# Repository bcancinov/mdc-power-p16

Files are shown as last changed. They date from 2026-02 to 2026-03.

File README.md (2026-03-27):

# mdc-power-p16
Modular Detector Controller Power 16V DC-DC Mezzanine Module

## Overview
12V input to 16V output DC-DC module, 0.5A nominal output, used as one of the `mdc-power-*` bias rails.
Designed for 2 MHz sync operation.
Mezzanine module.

## Power Stage
- Controller: `LT8350S` (`U1`)
  - 4-switch, single-inductor synchronous buck-boost controller (Silent Switcher 2 family).
  - Supports input above/below VOUT, suitable for regulated 16V from 12V input.
  - Silent Switcher 2 architecture for reduced EMI and cleaner switch-node behavior.
  - Single-inductor buck-boost topology simplifies power stage while handling input transients.
- Inductor: `L1` = `3.3uH`
  - Uses the XGL4020 shielded power inductor family (see `docs/xgl4020.pdf`).
  - Shielded construction to reduce radiated EMI and coupling into sensitive nodes.
  - Very low DCR family to reduce copper loss and improve efficiency.
  - Low AC loss construction optimized for high-frequency switching.

## Files
- Schematic: `power_p16.pdf`
- Simulation: `sim/` (LTspice and LTpowerCAD files used for loop and transient checks)

## Board Dimensions
- 44.8 mm x 41.5 mm

## Board Stackup
- 4-layer PCB

## CAD
- Designed using KiCad 9.

## Interface
- Control pins: `EN` (enable) and `PG` / `~PGOOD` (power good).
- Connector: `LSHM-140-04.0-L-DV-A-N-K-TR` (Samtec LSHM series) mezzanine for power and control signals.
  - Common pinout is shared across the 16V, -16V, 6V, and 3.3V variants.
  - Unused output rails are tied to GND on the specific module variant.

## Images
Layout:
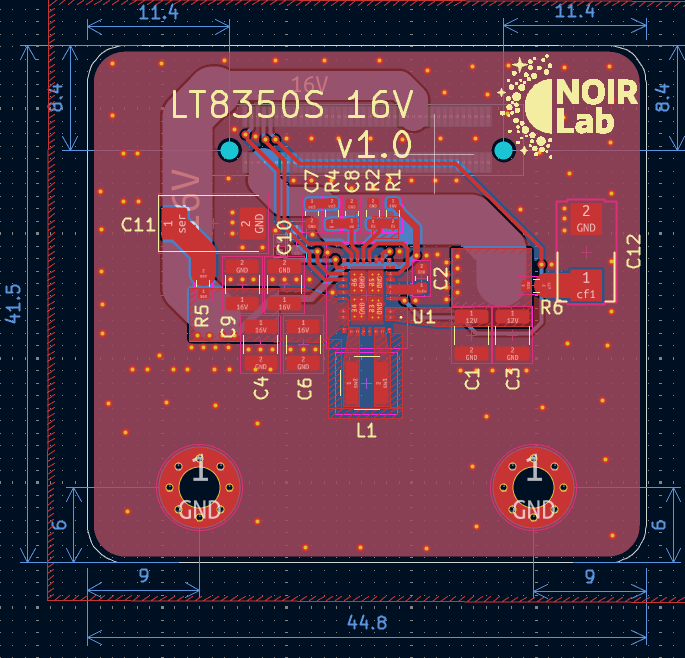
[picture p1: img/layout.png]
Layout


3D view:
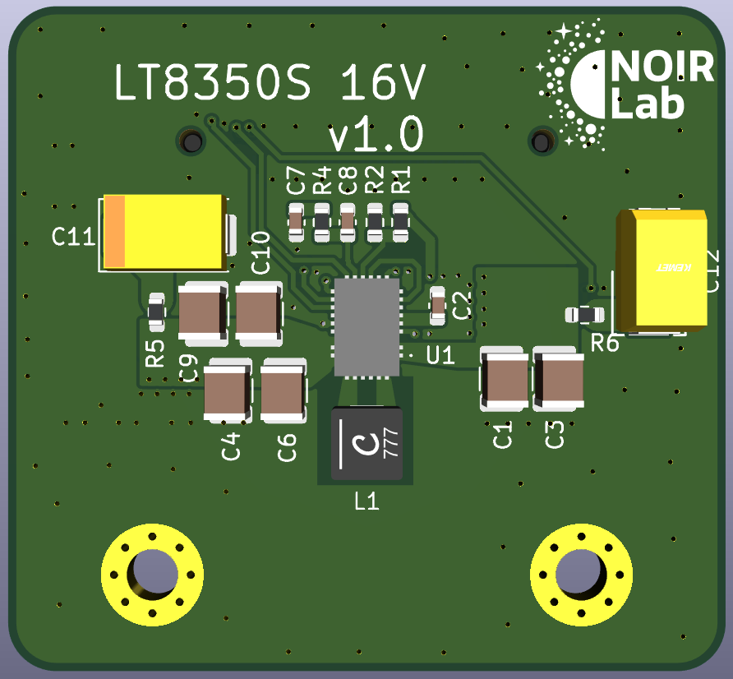
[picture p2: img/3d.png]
3D view


## License

This hardware design is licensed under the **Creative Commons Attribution-NonCommercial-ShareAlike 4.0 International License** (CC BY-NC-SA 4.0).

You are free to download, modify, and build upon this design for your own research or personal use, provided you give appropriate credit and share your modifications under the exact same license. **Commercial manufacturing or use of these designs is strictly prohibited without explicit permission.**

To view a copy of this license, visit [http://creativecommons.org/licenses/by-nc-sa/4.0/](http://creativecommons.org/licenses/by-nc-sa/4.0/) or see the `LICENSE` file in this repository.

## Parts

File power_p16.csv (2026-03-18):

Reference | Qty | MPN | M | Description
C1,C3 | 2 | GCM32ER71H475KA55K | Murata | 4.7 µF ±10% 50V Ceramic Capacitor X7R 1210 (3225 Metric)
C2 | 1 | GCM188R71E105KA64D | Murata | 1 µF ±10% 25V Ceramic Capacitor X7R 0603 (1608 Metric)
C4,C6,C9,C10 | 4 | TMK325ABJ476MM-P | TAIYO YUDEN | 47 µF ±20% 25V Ceramic Capacitor X5R 1210 (3225 Metric)
C5 | 1 | GCM155R71H104KE02J | MURATA | 0.1 µF ±10% 50V Ceramic Capacitor X7R 0402 (1005 Metric)
C7 | 1 | GRT1885C1E103FA02D | Murata | 10000 pF ±1% 25V Ceramic Capacitor C0G, NP0 0603 (1608 Metric)
C8 | 1 | CBR06C519C5GACAUTO | KEMET | 5.1 pF ±0.25pF 50V Ceramic Capacitor C0G, NP0 0603 (1608 Metric)
C11 | 1 | T521V226M025ATE040 | KEMET | 22 µF Molded Tantalum Polymer Capacitor 25 V 2917 (7343 Metric) 40mOhm @ 100kHz
C12 | 1 | T521X107M025ATE060 | Kemet | 100 µF Molded Tantalum Polymer Capacitor 25 V 2917 (7343 Metric) 60mOhm @ 100kHz
H1,H2 | 2 |  |  | Mounting Hole with connection
J1 | 1 | LSHM-140-04.0-L-DV-A-N-K-TR | Samtec | 80 Position Connector Self Mating, Non-Gendered, Hermaphroditic Surface Mount Gold
L1 | 1 | XGL4020-332MEC | Coilcraft | 3.3 µH Shielded Molded Inductor 6.6 A 34mOhm Max 1616 (4040 Metric)
R1 | 1 | ERA-3AEB114V | Panasonic | 110 kOhms ±0.1% 0.1W, 1/10W Chip Resistor 0603 (1608 Metric) Automotive AEC-Q200 Thin Film
R2 | 1 | ERA-3AEB7321V | Panasonic | 7.32 kOhms ±0.1% 0.1W, 1/10W Chip Resistor 0603 (1608 Metric) Automotive AEC-Q200 Thin Film
R3 | 1 | CRCW060320K0FKEA | VISHAY | 20 kOhms ±1% 0.1W, 1/10W Chip Resistor 0603 (1608 Metric) Automotive AEC-Q200 Thick Film
R4 | 1 | CRCW060347K5FKEA | Vishay | 47.5 kOhms ±1% 0.125W, 1/8W Chip Resistor 0603 (1608 Metric) Automotive AEC-Q200 Thick Film
R5,R6 | 2 | RCWE0603R500FKEA | Vishay | 500 mOhms ±1% 0.2W, 1/5W Chip Resistor 0603 (1608 Metric) Automotive AEC-Q200, Current Sense, Moisture Resistant Thick Film
U1 | 1 | LT8350SAV#PBF | Analog | Buck-Boost Switching Regulator IC Positive Adjustable 1V 1 Output 6A 32-TFQFN Exposed Pad, 28 Leads

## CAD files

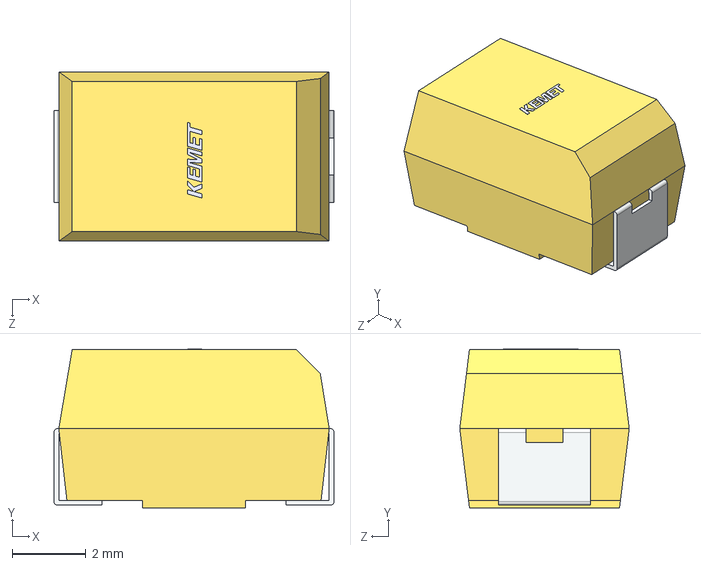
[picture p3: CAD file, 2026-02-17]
step/T521X.step
7.60 x 4.30 x 4.60 mm

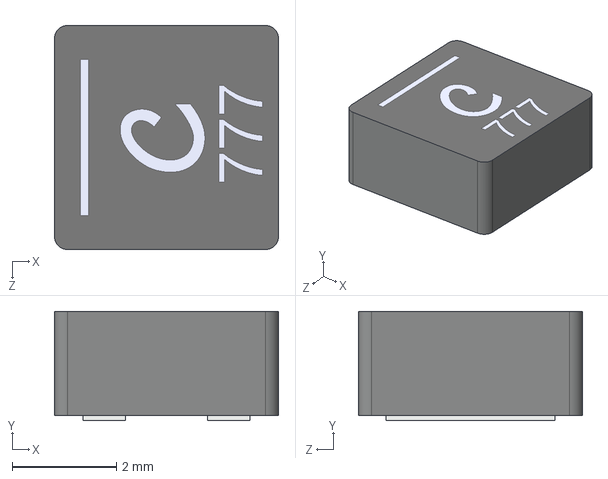
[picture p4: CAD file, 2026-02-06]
step/Coilcraft-XGL4020.step
4.30 x 2.10 x 4.30 mm

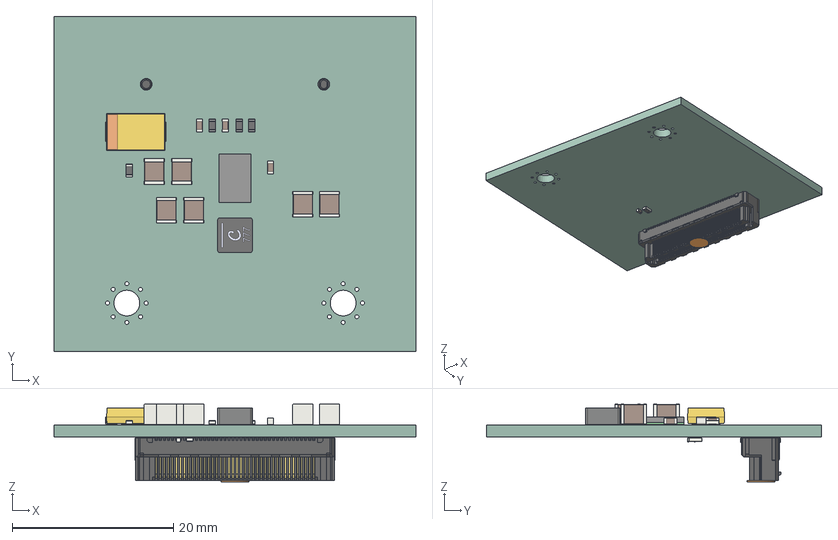
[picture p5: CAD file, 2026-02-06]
step/power_p16.step
44.8 x 41.5 x 9.63 mm
Coilcraft-XGL4020
C_1210_3225Metric x 6
R_0603_1608Metric x 5
C_0603_1608Metric x 3
CP_EIA-7343-20_Kemet-V
LT8350SAV#PBF
C_0402_1005Metric
LSHM-40-04.0-DV-A-N_STRIP
C-185--40-04.0-L-DV1P
C-185--40-04.0-DV1P2 L
K-DOT-.138-.250-.005.pp
power_p16_PCB

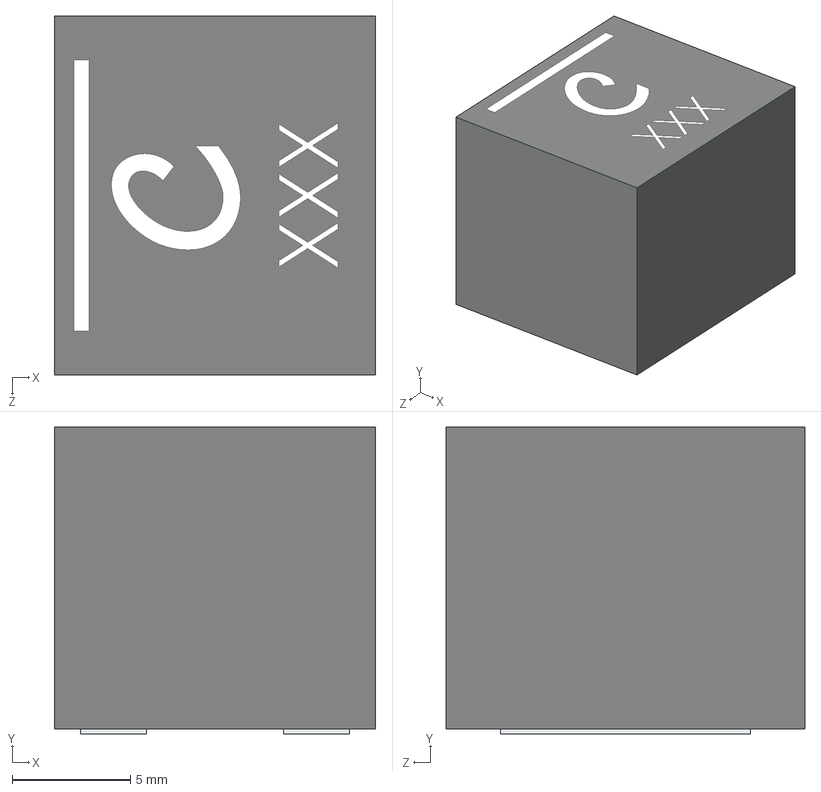
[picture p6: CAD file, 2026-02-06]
step/Coilcraft-XGL1313.step
13.6 x 13.0 x 15.2 mm

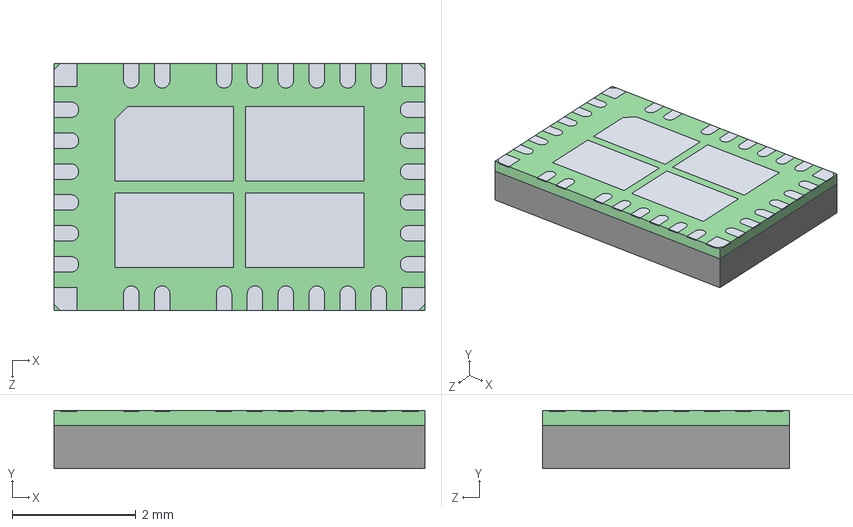
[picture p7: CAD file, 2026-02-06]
step/LT8350SAV#PBF.stp
6.00 x 0.94 x 4.00 mm

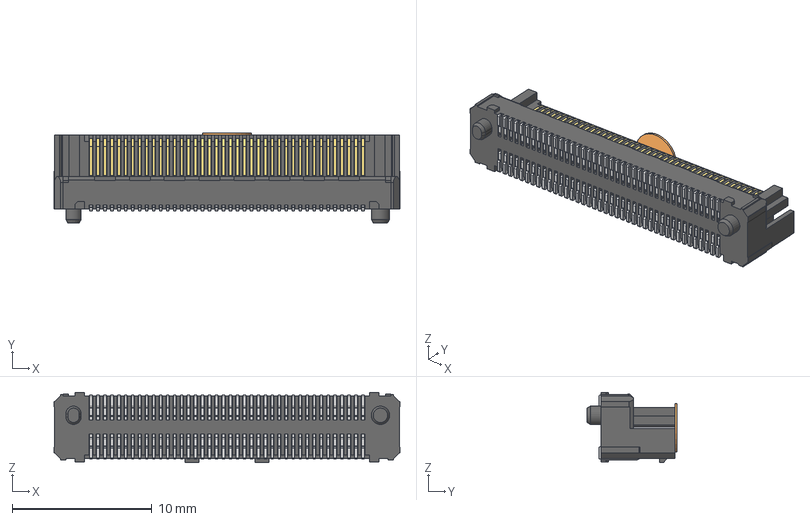
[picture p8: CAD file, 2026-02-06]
step/LSHM-140-04.0-L-DV-A-N-K-TR.stp
24.8 x 6.45 x 5.03 mm
LSHM-40-04.0-DV-A-N_STRIP
C-185--40-04.0-L-DV1P
C-185--40-04.0-DV1P2 L
K-DOT-.138-.250-.005.pp

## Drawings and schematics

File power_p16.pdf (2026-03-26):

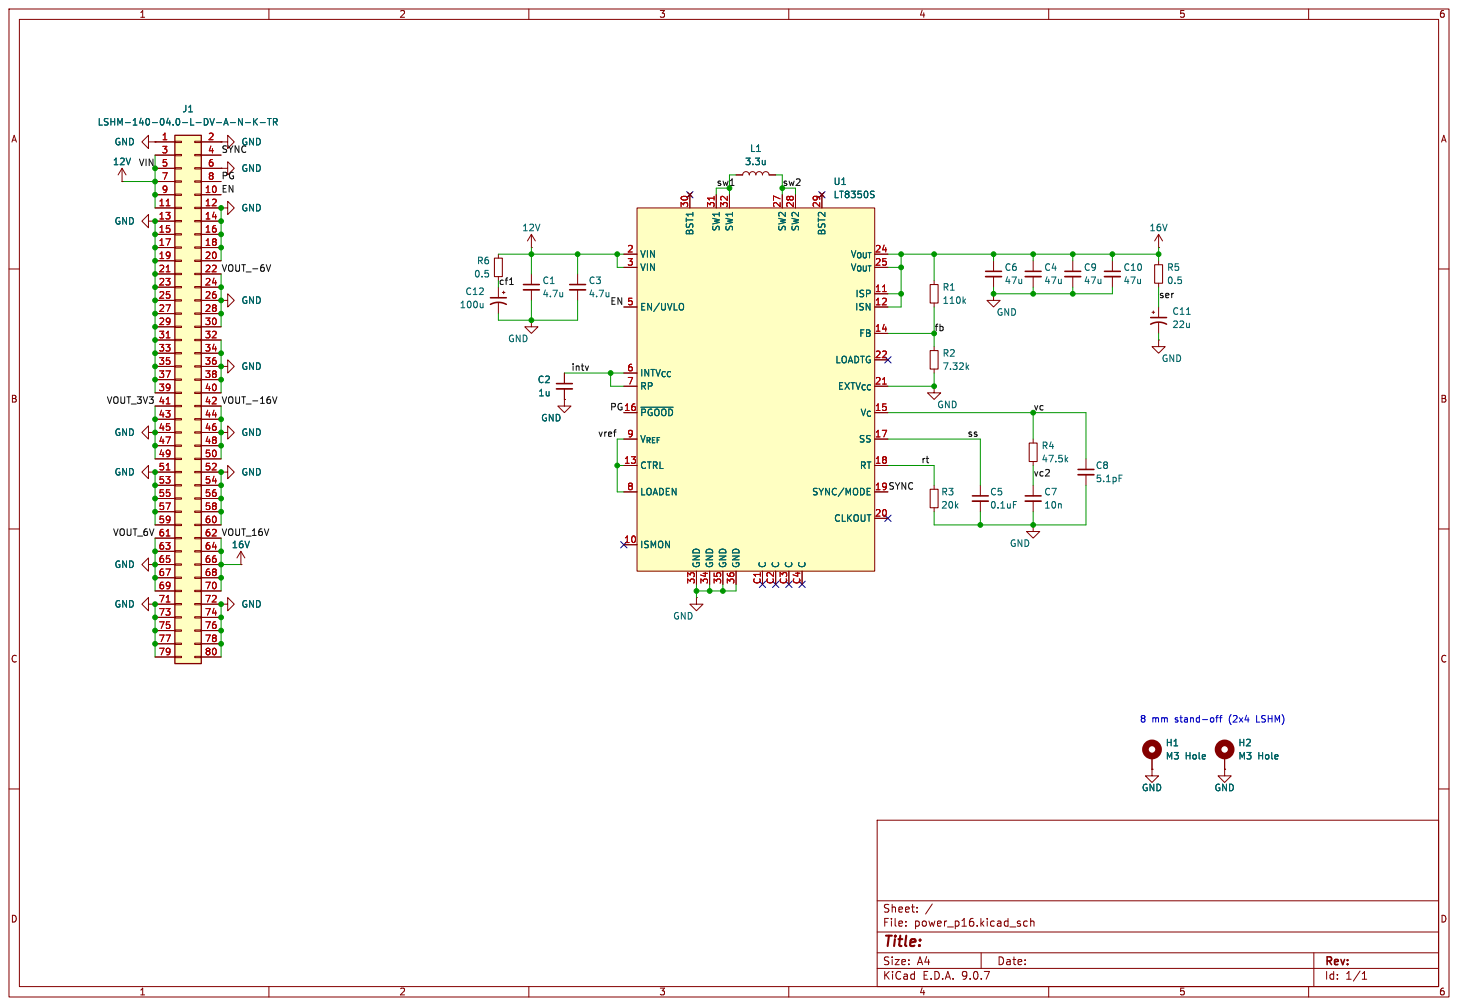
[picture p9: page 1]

Id: 1/1 Title: File: power_p16.kicad_sch Sheet: / GND

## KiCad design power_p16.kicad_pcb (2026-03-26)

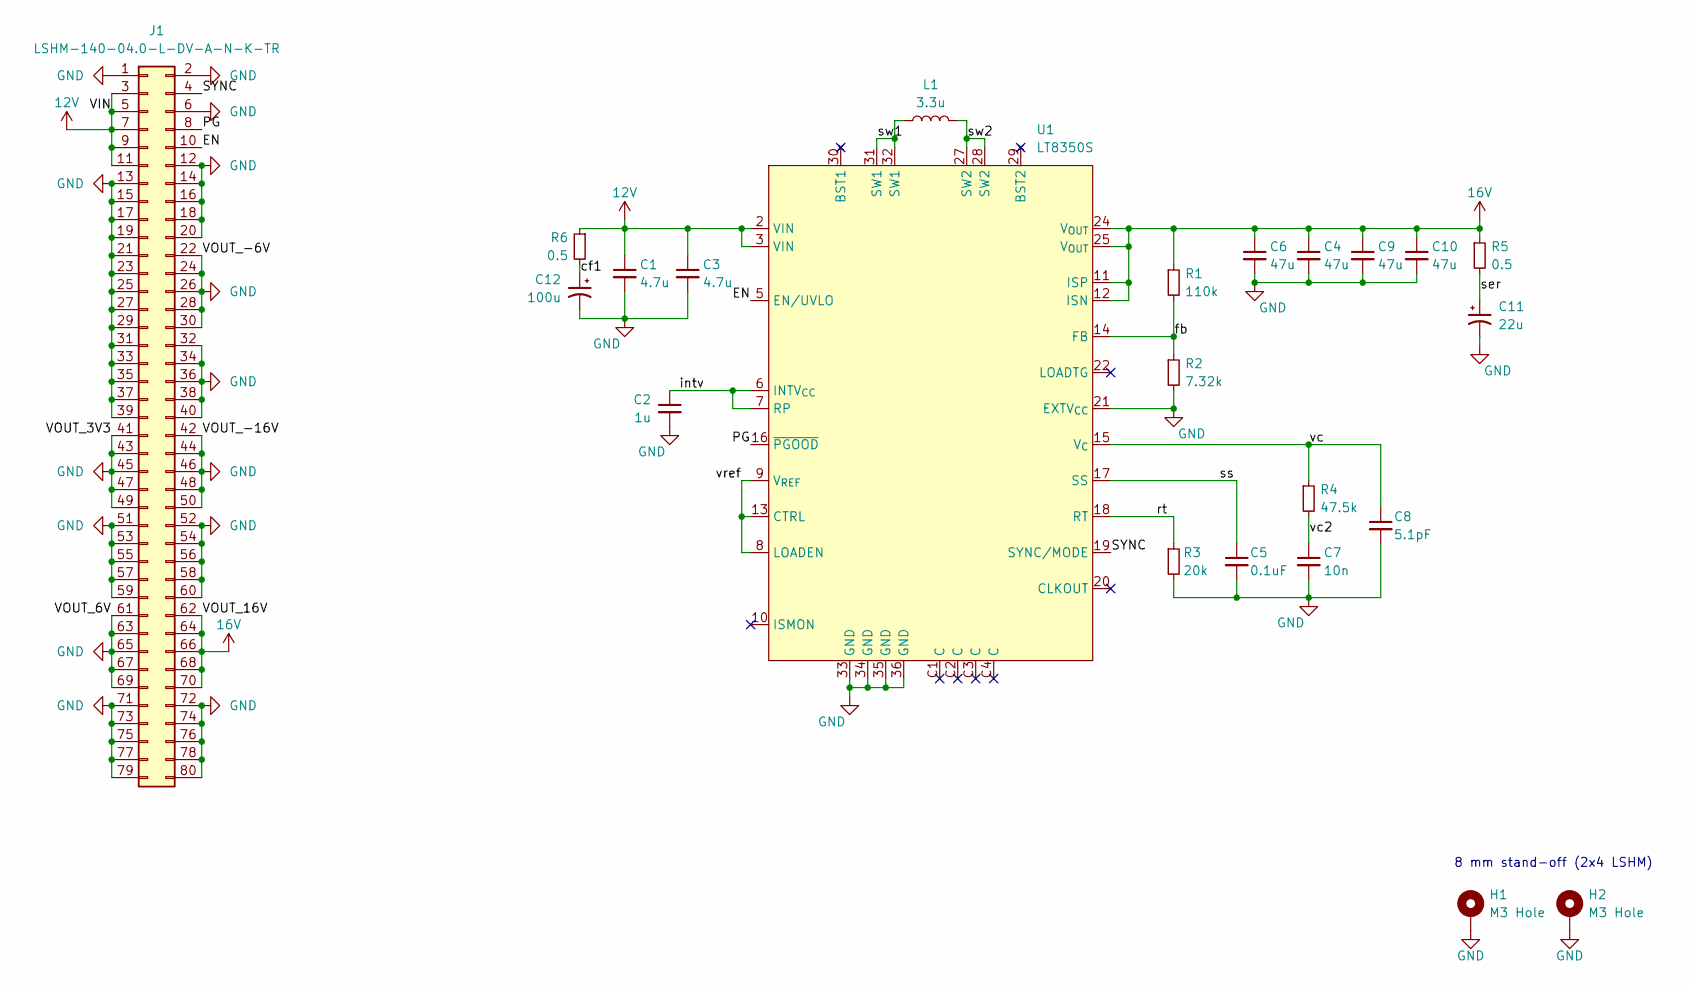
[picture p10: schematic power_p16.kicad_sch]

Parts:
C1, C3: 4.7u; C_1210_3225Metric; MPN GCM32ER71H475KA55K
C2: 1u; C_0603_1608Metric; MPN GCM188R71E105KA64D
C4, C6, C9, C10: 47u; C_1210_3225Metric; MPN TMK325ABJ476MM-P
C5: 0.1uF; C_0402_1005Metric; MPN GCM155R71H104KE02J
C7: 10n; C_0603_1608Metric; MPN GRT1885C1E103FA02D
C8: 5.1pF; C_0603_1608Metric; MPN CBR06C519C5GACAUTO
C11: 22u; CP_EIA-7343-20_Kemet-V; MPN T521V226M025ATE040
C12: 100u; T521X; MPN T521X107M025ATE060
H1, H2: M3 Hole; MountingHole_3.2mm_M3_Pad_Via
J1: LSHM-140-04.0-L-DV-A-N-K-TR; SAMTEC_LSHM-140-04.0-L-DV-A-N-K-TR; MPN LSHM-140-04.0-L-DV-A-N-K-TR
L1: 3.3u; XGL4020; MPN XGL4020-332MEC
R1: 110k; R_0603_1608Metric; MPN ERA-3AEB114V
R2: 7.32k; R_0603_1608Metric; MPN ERA-3AEB7321V
R3: 20k; R_0603_1608Metric; MPN CRCW060320K0FKEA
R4: 47.5k; R_0603_1608Metric; MPN CRCW060347K5FKEA
R5, R6: 0.5; R_0603_1608Metric; MPN RCWE0603R500FKEA
U1: LT8350S; MPN LT8350SAV#PBF

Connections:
12V: C1.1, C3.1, J1.3, J1.5, J1.7, J1.9, J1.11, R6.1, U1.2 (VIN), U1.3 (VIN)
16V: C4.1, C6.1, C9.1, C10.1, J1.62, J1.64, J1.66, J1.68, J1.70, R1.1, R5.1, U1.11 (ISP), U1.12 (ISN), U1.24 (V_{OUT}), U1.25 (V_{OUT})
/EN: J1.10, U1.5 (EN/UVLO)
/PG: J1.8, U1.16 (~PGOOD)
/SYNC: J1.4, U1.19 (SYNC/MODE)
/cf1: C12.1, R6.2
/fb: R1.2, R2.1, U1.14 (FB)
/intv: C2.1, U1.6 (INTV_{CC}), U1.7 (RP)
/rt: R3.1, U1.18 (RT)
/ser: C11.1, R5.2
/ss: C5.1, U1.17 (SS)
/sw1: L1.2, U1.31 (SW1), U1.32 (SW1)
/sw2: L1.1, U1.27 (SW2), U1.28 (SW2)
/vc: C8.1, R4.1, U1.15 (V_{C})
/vc2: C7.1, R4.2
/vref: U1.8 (LOADEN), U1.9 (V_{REF}), U1.13 (CTRL)
GND: C1.2, C2.2, C3.2, C4.2, C5.2, C6.2, C7.2, C8.2, C9.2, C10.2, C11.2, C12.2, H1.1, H2.1, J1.1, J1.2, J1.6, J1.12, J1.13, J1.14, J1.15, J1.16, J1.17, J1.18, J1.19, J1.20, J1.21, J1.22, J1.23, J1.24, J1.25, J1.26, J1.27, J1.28, J1.29, J1.30, J1.31, J1.32, J1.33, J1.34, J1.35, J1.36, J1.37, J1.38, J1.39, J1.40, J1.41, J1.42, J1.43, J1.44, J1.45, J1.46, J1.47, J1.48, J1.49, J1.50, J1.51, J1.52, J1.53, J1.54, J1.55, J1.56, J1.57, J1.58, J1.59, J1.60, J1.61, J1.63, J1.65, J1.67, J1.69, J1.71, J1.72, J1.73, J1.74, J1.75, J1.76, J1.77, J1.78, J1.79, J1.80, R2.2, R3.2, U1.21 (EXTV_{CC}), U1.33 (GND), U1.34 (GND), U1.35 (GND), U1.36 (GND)

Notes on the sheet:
8 mm stand-off (2x4 LSHM)

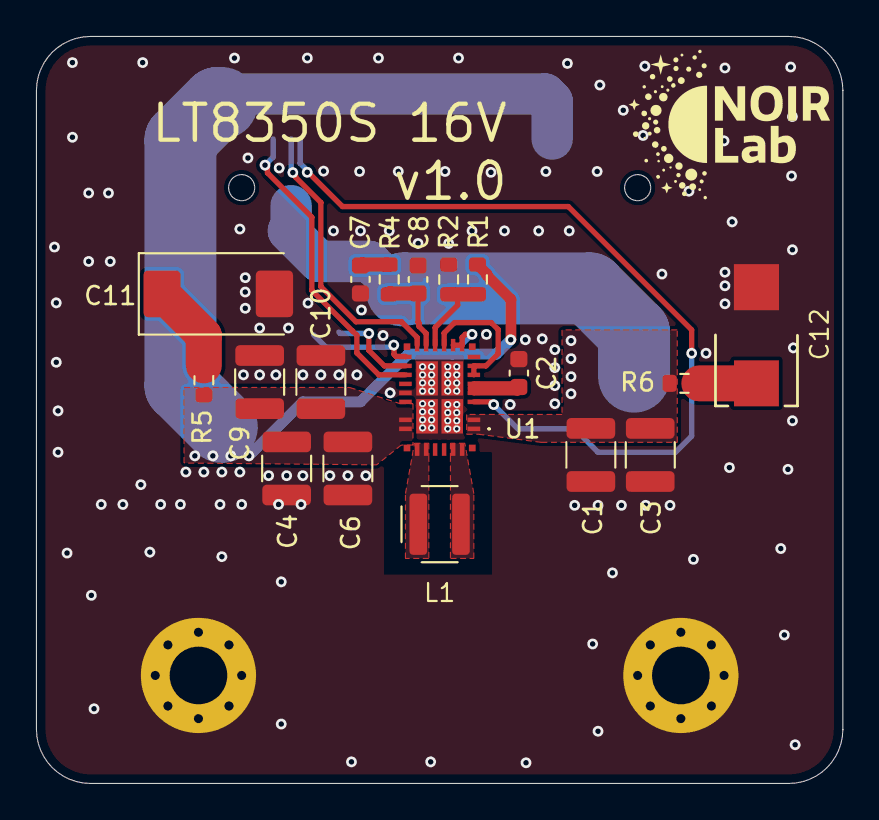
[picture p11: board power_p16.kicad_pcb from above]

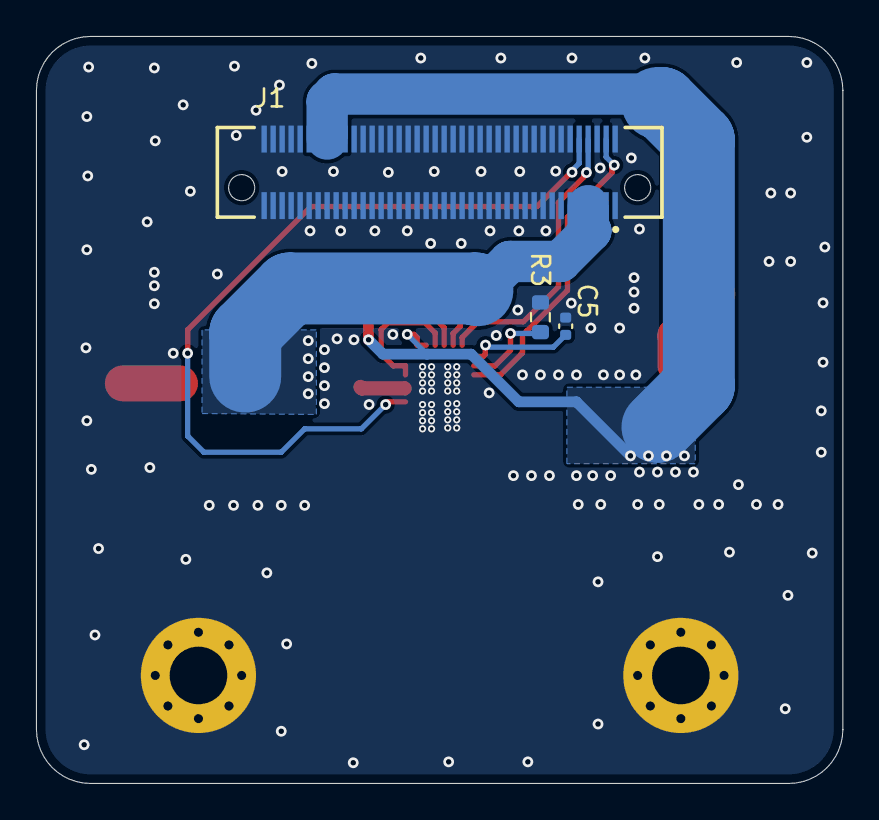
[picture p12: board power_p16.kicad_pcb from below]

Board: 4 copper layers, 44.8 x 41.5 mm, 23 parts (3 on the bottom side), 17 nets.

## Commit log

2026-02-17 Add input RC snubber
    [T521X.step, power_p16.csv, power_p16.kicad_pcb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]
2026-03-18 update feedback resistor to thin film
    [power_p16.csv, power_p16.kicad_pcb, power_p16.kicad_sch]

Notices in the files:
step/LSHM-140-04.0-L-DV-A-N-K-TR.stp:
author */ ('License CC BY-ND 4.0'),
